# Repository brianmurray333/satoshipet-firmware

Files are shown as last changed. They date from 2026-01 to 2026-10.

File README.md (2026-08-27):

<h1 align="center">🐱⚡ Satoshi Pet Firmware</h1>

<p align="center">
  <strong>A cute hardware companion that reacts to your Bitcoin activity</strong>
</p>

<p align="center">
  <a href="#features">Features</a> •
  <a href="#hardware">Hardware</a> •
  <a href="#build-your-own">Build Your Own</a> •
  <a href="#flashing">Flashing</a> •
  <a href="#connecting">Connecting</a> •
  <a href="#license">License</a>
</p>

---

## What is Satoshi Pet?

Satoshi Pet is an open-source hardware device that makes Bitcoin tangible and fun. It's a virtual pet that lives on a small OLED screen and reacts to your Bitcoin balance:

- 🎉 **Celebrates** when you earn sats
- 🍕 **Needs feeding** with coins you earn
- 🎮 **Plays games** to stay happy
- 💤 **Sleeps** to save battery
- 📱 **Syncs** with your [Ganamos](https://ganamos.earth) wallet

Perfect for teaching kids about Bitcoin through interactive play, or just having a fun desk companion that shows your stack!

## Features

- **Real-time Balance Updates** - Your pet knows when you earn or spend sats
- **Virtual Economy** - Earn coins by earning Bitcoin, spend them on pet care
- **Mini Games** - Lightning-themed games to keep your pet happy
- **Job Notifications** - Get pinged when new jobs are posted in your groups
- **Battery Powered** - USB-C rechargeable, lasts for days
- **WiFi Connected** - Syncs automatically with your Ganamos account
- **Open Source** - Build your own from off-the-shelf parts!

## Hardware

### Bill of Materials (BOM)

| Part | Specification | Est. Cost | Where to Buy |
|---|---|---|---|
| **Heltec WiFi Kit 32 V3** | ESP32-S3 with 0.96" OLED | $15-20 | [AliExpress](https://www.aliexpress.com/item/1005006439587092.html), [Amazon](https://www.amazon.com/dp/B0BKVKVQ4S) |
| **LiPo Battery** | 3.7V, 1000-2000mAh, JST-PH 2.0 connector | $5-10 | Amazon, AliExpress |
| **Tactile Button** | 6mm through-hole (optional, for external button) | $0.50 | Any electronics store |
| **Piezo Buzzer** | 5V passive buzzer | $1 | Amazon, AliExpress |
| **3D Printed Case** | PLA filament | $2-5 | Print yourself or use a service |
| **USB-C Cable** | For charging and flashing | $3 | Anywhere |

**Total estimated cost: $25-40**

### Wiring Diagram

```
Heltec WiFi Kit 32 V3
├── GPIO 0  ← Built-in PRG button (primary button)
├── GPIO 2  ← External button (optional)
├── GPIO 48 → Piezo buzzer positive (+)
├── GND     → Piezo buzzer negative (-)
└── Battery → 3.7V LiPo via JST connector
```

The Heltec board has a built-in OLED display, so no additional wiring needed for the screen!

### 3D Printed Case

STL files for the enclosure are in the [`hardware/3d-models/`](hardware/3d-models/) directory:
- `case-top.stl` - Top shell
- `case-bottom.stl` - Bottom shell with battery compartment
- `button-cap.stl` - Optional button cap

Print settings: PLA, 0.2mm layer height, 20% infill

## Build Your Own

### Prerequisites

1. **Arduino IDE 2.x** or **PlatformIO**
2. **ESP32 Board Support** - Add Heltec ESP32 to your Arduino boards manager
3. **Required Libraries**:
   - `WiFiManager` by tzapu
   - `ArduinoJson` by Benoit Blanchon
   - `Heltec ESP32 Dev-Boards` board package

### Arduino IDE Setup

1. **Add Heltec Board Manager URL:**
   ```
   File → Preferences → Additional Board Manager URLs:
   https://github.com/Heltec-Aaron-Lee/WiFi_Kit_series/releases/download/0.0.9/package_heltec_esp32_index.json
   ```

2. **Install Board Package:**
   ```
   Tools → Board → Boards Manager → Search "Heltec" → Install
   ```

3. **Select Board:**
   ```
   Tools → Board → Heltec ESP32 Series Dev-Boards → WiFi Kit 32(V3)
   ```

4. **Install Libraries:**
   ```
   Tools → Manage Libraries → Search and install:
   - WiFiManager
   - ArduinoJson
   ```

## Flashing

1. Connect your Heltec board via USB-C

2. Open `firmware/satoshi_pet_heltec.ino` in Arduino IDE

3. Select the correct port:
   ```
   Tools → Port → /dev/cu.usbserial-* (Mac) or COM* (Windows)
   ```

4. Click **Upload** (→ button)

5. Wait for flashing to complete (~30 seconds)

## Connecting

### First-Time Setup

1. **Power on** your freshly flashed device
2. **Connect to WiFi**: The device creates a hotspot called `SatoshiPet-Setup`
   - Connect to this WiFi from your phone/laptop
   - A captive portal opens - enter your home WiFi credentials
3. **Get Pairing Code**: Device displays a 6-character code
4. **Link to Ganamos**:
   - Go to [ganamos.earth/connect-pet](https://ganamos.earth/connect-pet)
   - Create an account if you don't have one
   - Enter the pairing code to link your device

### Reconnecting

If you change WiFi networks:
1. Hold the button for 5+ seconds
2. Device enters WiFi setup mode
3. Connect to `SatoshiPet-Setup` and enter new credentials

## How It Works

```
┌─────────────────┐         ┌─────────────────┐
│  Satoshi Pet    │ ←WiFi→  │   Ganamos.earth │
│  (ESP32 Device) │         │   (Backend)     │
└────────┬────────┘         └────────┬────────┘
         │                           │
         │  1. Fetch config          │
         │  ──────────────────────→  │
         │  (balance, coins, jobs)   │
         │  ←──────────────────────  │
         │                           │
         │  2. Spend coins           │
         │  ──────────────────────→  │
         │  (feed, play game)        │
         │  ←──────────────────────  │
         │                           │
         │  3. Submit game score     │
         │  ──────────────────────→  │
         │  (leaderboard update)     │
         │  ←──────────────────────  │
         │                           │
```

The device polls the Ganamos API every 20-30 seconds to:
- Check your current balance
- Receive new coins when you earn Bitcoin
- Get notified of new jobs
- Sync pet care actions

## API Endpoints

The firmware communicates with these public endpoints:

| Endpoint | Purpose |
|---|---|
| `GET /api/device/config` | Fetch balance, coins, notifications |
| `POST /api/device/spend-coins` | Spend coins for feeding/games |
| `POST /api/device/game-score` | Submit game high scores |
| `GET /api/device/jobs` | Fetch available jobs |
| `POST /api/device/job-complete` | Mark a job as completed |

Note: Device identity is now sent in HTTP headers (`X-Device-Id`, `X-Pairing-Code`). The `deviceId` query parameter remains temporarily for one release to maintain compatibility with existing devices and backend versions.
## Troubleshooting

### Device won't connect to WiFi
- Hold button 5+ seconds to enter WiFi setup mode
- Make sure you're connecting to 2.4GHz network (not 5GHz)

### Pairing code not accepted
- Make sure you're entering the code exactly as shown
- Try power cycling the device to generate a new code

### Pet shows wrong balance
- Balance syncs every 20-30 seconds
- Check your internet connection
- Try pressing the button to force a refresh

### Screen stays off
- Device enters power-save mode after inactivity
- Press any button to wake up
- Check battery charge level

## Contributing

We welcome contributions! Please:

1. Fork this repository
2. Create a feature branch (`git checkout -b feature/amazing-feature`)
3. Commit your changes (`git commit -m 'Add amazing feature'`)
4. Push to the branch (`git push origin feature/amazing-feature`)
5. Open a Pull Request

## Community

- 🌐 **Website**: [satoshipet.com](https://satoshipet.com)
- 💬 **Discord**: Coming soon
- 🐦 **Twitter**: [@SatoshiPet](https://twitter.com/SatoshiPet)

## License

This project uses dual licensing:

- **Firmware** (`/firmware/*`): [Apache License 2.0](LICENSE) - Free to use, modify, and distribute with attribution
- **Hardware** (`/hardware/*`): [CERN-OHL-P v2](hardware/LICENSE-HARDWARE) - Open hardware license with patent protection

## Disclaimer

Satoshi Pet is a fun educational device. It does NOT store any Bitcoin private keys or have access to your funds. It only displays your Ganamos balance and reacts to changes.

---

<p align="center">
  Made with ❤️ by <a href="https://ganamos.earth">Ganamos</a>
</p>

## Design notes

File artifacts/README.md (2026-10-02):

# Battery and UX display previews

These images are code-based previews using the Heltec bitmap fonts and 128×64 layout, not live simulator screenshots. Values on the home screen are illustrative.

`ui-preview.png` shows the offline home screen, menu guidance, and hold confirmation from left to right. Individual previews also include the partially filled hold indicator.

Both firmware targets compile and the host regression checks pass. Live simulator verification was blocked by an expired Wokwi license. Battery current, GPIO wake behavior, and interaction timing still need validation on physical hardware.

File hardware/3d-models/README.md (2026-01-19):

# 3D Print Files

This folder contains STL files for the Satoshi Pet enclosure.

## Files

| File | Description |
|---|---|
| `case-top.stl` | Top shell with display cutout |
| `case-bottom.stl` | Bottom shell with battery compartment |
| `button-cap.stl` | Optional button extension |

## Print Settings

| Setting | Recommended |
|---|---|
| Material | PLA or PETG |
| Layer Height | 0.2mm |
| Infill | 15-20% |
| Supports | Yes (for button cutout) |
| Walls | 2-3 perimeters |

## Assembly

1. Print all parts
2. Insert Heltec board into bottom shell
3. Route battery and buzzer wires
4. Snap or screw top shell in place
5. (Optional) Add button cap

## Customization

STEP files are provided for modification. You can:
- Adjust dimensions for different batteries
- Add ventilation holes
- Customize button placement
- Add belt clip or lanyard hole

## Contributing

Have a better case design? PRs welcome!

---

**Note:** STL files will be added soon. For now, you can use the device without a case for testing.

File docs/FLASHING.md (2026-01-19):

# Flashing Guide

This guide walks you through flashing the Satoshi Pet firmware to a Heltec WiFi Kit 32 V3 board.

## Prerequisites

### Option 1: Arduino IDE (Recommended for beginners)

1. **Download Arduino IDE 2.x**
   - [arduino.cc/en/software](https://www.arduino.cc/en/software)

2. **Add Heltec Board Support**
   - Open Arduino IDE
   - Go to `File → Preferences`
   - In "Additional Board Manager URLs", add:
     ```
     https://github.com/Heltec-Aaron-Lee/WiFi_Kit_series/releases/download/0.0.9/package_heltec_esp32_index.json
     ```
   - Click OK

3. **Install Heltec ESP32 Board Package**
   - Go to `Tools → Board → Boards Manager`
   - Search for "Heltec"
   - Install "Heltec ESP32 Series Dev-Boards"

4. **Install Required Libraries**
   - Go to `Tools → Manage Libraries`
   - Install these libraries:
     - **WiFiManager** by tzapu (version 2.0.x)
     - **ArduinoJson** by Benoit Blanchon (version 7.x)

### Option 2: PlatformIO (Recommended for developers)

1. Install [VS Code](https://code.visualstudio.com/)
2. Install [PlatformIO Extension](https://platformio.org/install/ide?install=vscode)
3. Libraries will be installed automatically from `platformio.ini`

## Flashing Steps

### Step 1: Connect Your Board

1. Connect the Heltec WiFi Kit 32 V3 to your computer via USB-C
2. Wait for drivers to install (usually automatic)

### Step 2: Select Board and Port

**Arduino IDE:**
- `Tools → Board → Heltec ESP32 Series Dev-Boards → WiFi Kit 32(V3)`
- `Tools → Port → Select your port`
  - Mac: `/dev/cu.usbserial-*` or `/dev/cu.wchusbserial*`
  - Windows: `COM3`, `COM4`, etc.
  - Linux: `/dev/ttyUSB0` or `/dev/ttyACM0`

**PlatformIO:**
- The board is auto-detected, just click the Upload button

### Step 3: Open the Firmware

1. Open the `firmware/satoshi_pet_heltec.ino` file in Arduino IDE
2. All the `.cpp` and `.h` files in the same folder will be included automatically

### Step 4: Upload

**Arduino IDE:**
- Click the Upload button (→ arrow icon)
- Wait for compilation and upload (~30-60 seconds)
- You should see "Done uploading" when complete

**PlatformIO:**
- Click the Upload button in the bottom toolbar
- Or run `pio run --target upload`

### Step 5: Verify

1. Open Serial Monitor (`Tools → Serial Monitor`)
2. Set baud rate to `115200`
3. You should see boot messages and "Setup complete!"

## Troubleshooting

### "Port not found" or "No device detected"

1. Try a different USB cable (some cables are charge-only)
2. Try a different USB port
3. Install CH340 drivers manually:
   - [Windows Driver](http://www.wch.cn/download/CH341SER_EXE.html)
   - [Mac Driver](http://www.wch.cn/download/CH341SER_MAC_ZIP.html)

### "Upload failed" or "Timed out waiting for packet header"

1. Hold the `PRG` button on the board while clicking Upload
2. Release the button after you see "Connecting..."
3. Some boards require this manual boot mode entry

### "Board not supported" error

Make sure you installed the Heltec ESP32 board package, NOT the generic ESP32 package.

### Compilation errors

1. Make sure all files are in the same folder as `satoshi_pet_heltec.ino`
2. Make sure you installed both required libraries (WiFiManager, ArduinoJson)
3. Try `Sketch → Verify/Compile` first to see detailed errors

## First Boot

After successful flashing:

1. The board will display a splash screen
2. Then it will create a WiFi hotspot called `SatoshiPet-Setup`
3. Connect to this WiFi from your phone/laptop
4. A captive portal will open - enter your home WiFi credentials
5. The device will restart and display a 6-character pairing code

See the main README for pairing instructions.

## Updating Firmware

To update an already-configured device:

1. The device will remember WiFi credentials after update
2. Just flash the new firmware using the same steps above
3. Your pairing will be preserved (stored in flash memory)

## Factory Reset

To completely reset the device:

1. Hold the external button for 10+ seconds
2. The device will prompt "Factory Reset?"
3. Select "Yes" to confirm
4. All settings (WiFi, pairing) will be erased

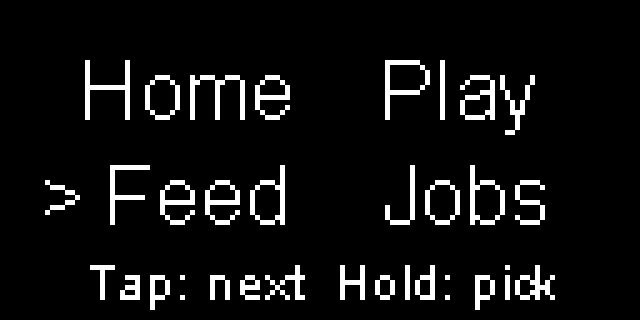
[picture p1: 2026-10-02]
artifacts/menu-preview.png

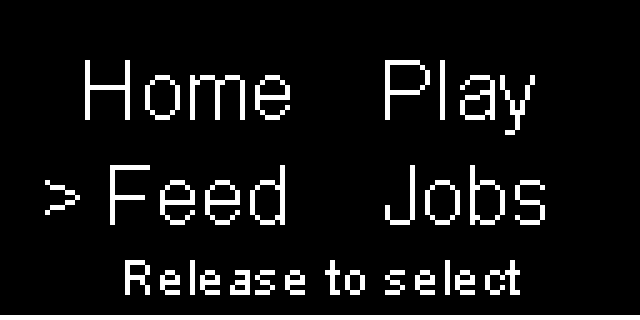
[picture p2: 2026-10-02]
artifacts/ready-preview.png

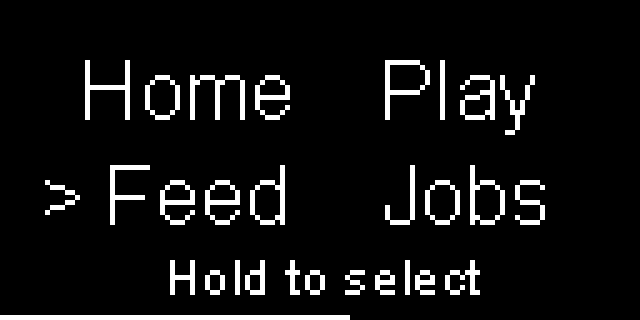
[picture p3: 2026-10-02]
artifacts/hold-preview.png

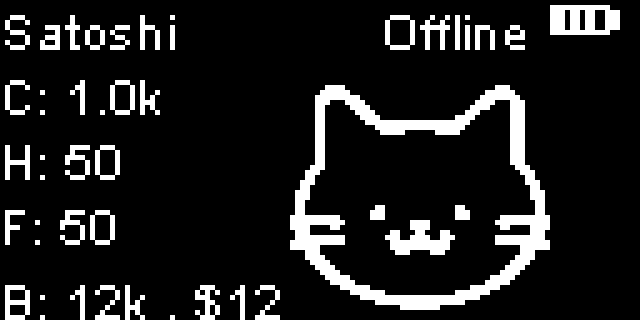
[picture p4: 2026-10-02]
artifacts/home-preview.png

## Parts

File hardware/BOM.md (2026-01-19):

# Bill of Materials (BOM)

Complete parts list for building your own Satoshi Pet.

## Core Components

### 1. Heltec WiFi Kit 32 V3

**The main board - ESP32-S3 with built-in OLED display**

| Spec | Value |
|---|---|
| MCU | ESP32-S3 |
| Display | 0.96" 128x64 OLED (SSD1306) |
| WiFi | 2.4GHz 802.11 b/g/n |
| USB | USB-C (programming & charging) |
| Battery | Built-in LiPo charger (JST-PH 2.0) |

**Where to Buy:**
- [Amazon US (Recommended)](https://www.amazon.com/dp/B07DKD79Y9?th=1) - ~$18
- [AliExpress - Official Heltec Store](https://www.aliexpress.com/item/1005006439587092.html) - ~$15

**⚠️ Important:** Make sure to get the **V3** version (ESP32-S3), not V2 or V1.

---

### 2. LiPo Battery

**3.7V Lithium Polymer battery with JST-PH 2.0mm connector**

| Spec | Recommended |
|---|---|
| Voltage | 3.7V (single cell) |
| Capacity | 1000-2000mAh |
| Connector | JST-PH 2.0mm (2-pin) |
| Size | ~50x30x8mm or smaller |

**Where to Buy:**
- [Amazon US (Recommended)](https://www.amazon.com/dp/B0FMY3M1YX?th=1) - ~$8
- [Adafruit 2000mAh](https://www.adafruit.com/product/2011) - $12
- Search "3.7V LiPo JST-PH 2.0" on AliExpress for cheaper options

**Battery Life Estimates:**
| Capacity | Active Use | Sleep Mode |
|---|---|---|
| 1000mAh | ~8 hours | ~3 days |
| 2000mAh | ~16 hours | ~7 days |

---

### 3. Piezo Buzzer

**5V passive piezo buzzer for sound effects**

| Spec | Value |
|---|---|
| Type | Passive (tone-driven) |
| Voltage | 3.3V-5V |
| Size | ~12mm diameter |

**Where to Buy:**
- [Amazon US (Recommended) - 10 pack](https://www.amazon.com/dp/B01N7NHSY6) - ~$6

**Note:** The firmware works with both active and passive buzzers. Active buzzers are simpler to use.

---

## Optional Components

### 4. External Button (Optional)

**Additional tactile button for easier pressing**

The Heltec board has a built-in PRG button (GPIO 0), but you can add an external button for a better case design.

| Spec | Value |
|---|---|
| Type | Tactile momentary switch |
| Size | 6mm x 6mm |
| Connection | Normally open (NO) |

**Where to Buy:**
- [Amazon US (Recommended)](https://www.amazon.com/dp/B07GN1K4HG) - ~$6

**Wiring:** Connect between GPIO 2 and GND (pull-up is internal).

---

### 5. Jumper Wires

**For connecting buzzer and button to the board**

| Spec | Value |
|---|---|
| Type | Male-to-female or male-to-male |
| Quantity | 4-6 wires needed |

**Where to Buy:**
- [Amazon US (Recommended)](https://www.amazon.com/EDGELEC-Breadboard-Optional-Assorted-Multicolored/dp/B07GD2BWPY) - ~$7

---

### 5. 3D Printed Case

**Enclosure to protect and display your Satoshi Pet**

| Spec | Recommended |
|---|---|
| Material | PLA or PETG |
| Layer Height | 0.2mm |
| Infill | 15-20% |
| Supports | May be needed for button cutout |

**Options:**
1. **Print yourself** - STL files in `hardware/3d-models/`
2. **Use a service** - Upload to JLCPCB, Shapeways, or local maker space
3. **Skip it** - The bare board works fine for testing!

---

## Tools Needed

| Tool | Purpose |
|---|---|
| Soldering iron | Connect buzzer wires |
| Solder | For buzzer connection |
| Wire (22-26 AWG) | Connect buzzer to board |
| USB-C cable | Programming and charging |
| Computer | For flashing firmware |

---

## Total Cost Estimate

| Item | Est. Cost |
|---|---|
| Heltec WiFi Kit 32 V3 | ~$18 |
| LiPo Battery | ~$8 |
| Buzzer (10 pack) | ~$6 |
| Buttons (pack) | ~$6 |
| Jumper Wires | ~$7 |
| 3D Printed Case | ~$2-5 |
| **Total** | **~$45-50** |

**Note:** Many parts come in multi-packs, so the per-unit cost is lower if building multiple devices. Sharing packs with friends can bring individual cost down to ~$30.

---

## Sourcing Tips

1. **AliExpress** - Cheapest, but 2-4 week shipping
2. **Amazon** - Fast shipping, slightly more expensive
3. **Adafruit/SparkFun** - Best quality, good documentation
4. **Local electronics store** - Immediate, but limited selection

## Alternative Boards

The firmware is designed for Heltec WiFi Kit 32 V3, but could be adapted for:

| Board | Compatibility | Notes |
|---|---|---|
| Heltec WiFi Kit 32 V2 | ⚠️ Partial | Different pin mapping |
| LILYGO T-Display S3 | ⚠️ Partial | Different display library |
| Generic ESP32 + SSD1306 | ⚠️ Partial | Manual wiring needed |

For best results, use the recommended Heltec WiFi Kit 32 V3.

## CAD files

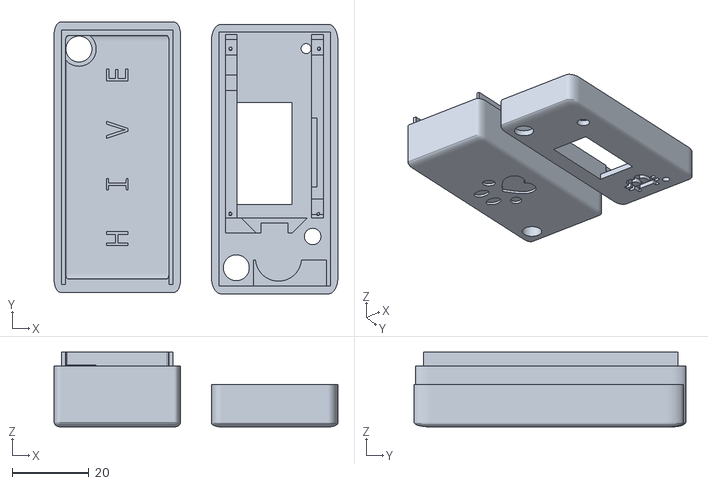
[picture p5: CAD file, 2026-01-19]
hardware/3d-models/case-v1.stl
74.0 x 70.8 x 19.5

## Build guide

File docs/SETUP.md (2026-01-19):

# Setup Guide

Complete guide to setting up your Satoshi Pet from scratch.

## Part 1: Hardware Assembly

### Required Parts

| Part | Notes |
|---|---|
| Heltec WiFi Kit 32 V3 | Main board with built-in OLED |
| 3.7V LiPo Battery | 1000-2000mAh recommended |
| Piezo Buzzer | 5V passive buzzer for sounds |
| 3D Printed Case | Optional but recommended |

### Wiring

```
Heltec Board          Component
────────────         ──────────
GPIO 48  ──────────► Buzzer (+)
GND      ──────────► Buzzer (-)
Battery Connector ◄── LiPo Battery (JST-PH 2.0)
```

**Note:** The Heltec board has a built-in battery connector and charging circuit. Just plug in the battery!

### Assembly

1. **Test before assembly** - Flash the firmware and test everything works
2. **Connect buzzer** - Solder wires to GPIO 48 (+) and GND (-)
3. **Connect battery** - Plug into the JST connector on the board
4. **Place in case** - Secure with screws or friction fit
5. **Done!**

## Part 2: First Boot

### Step 1: Power On

Press the reset button or plug in USB-C. You'll see:

1. **Ganamos splash logo** (2.5 seconds)
2. **"Fix your community / Earn Bitcoin"** tagline (2.5 seconds)
3. **WiFi Setup screen**

### Step 2: Configure WiFi

1. On your phone/laptop, look for WiFi network: `SatoshiPet-Setup`
2. Connect to it (no password needed)
3. A captive portal will automatically open
   - If it doesn't, open a browser and go to `192.168.4.1`
4. Click "Configure WiFi"
5. Select your home WiFi network
6. Enter the password
7. Click "Save"

The device will restart and connect to your WiFi.

### Step 3: Get Pairing Code

Once connected to WiFi, the device displays:

```
┌────────────────────┐
│   Pairing Code:    │
│                    │
│      ABC123        │
│                    │
│ Enter in Ganamos   │
└────────────────────┘
```

Write down this 6-character code.

### Step 4: Create Ganamos Account

1. Go to [ganamos.earth](https://ganamos.earth)
2. Click "Sign Up" and create an account
3. Verify your email

### Step 5: Connect Your Pet

1. Go to [ganamos.earth/connect-pet](https://ganamos.earth/connect-pet)
2. Enter the 6-character pairing code from your device
3. Choose a name for your pet
4. Select a pet type (cat, dog, rabbit, etc.)
5. Click "Connect"

Your device will show "Connected!" and your pet will appear!

## Part 3: Daily Use

### Button Controls

| Action | What Happens |
|---|---|
| **Short press** | Open menu |
| **Hold (3 sec)** | Select menu item / WiFi setup (if disconnected) |
| **Hold (10 sec)** | Factory reset prompt |

### Menu Options

- **Home** - Return to pet view
- **Play** - Play the Lightning Game (costs coins)
- **Feed** - Feed your pet (costs coins)
- **Jobs** - View available jobs

### Earning Coins

Coins are earned automatically when you:
- Receive Bitcoin deposits
- Get paid for completing jobs
- Receive internal transfers

Every sat you earn = coins for your pet!

### Pet Stats

- **Hunger** - Decreases over time, feed to restore
- **Happiness** - Decreases over time, play games to restore
- **Coins** - Your spendable balance for pet care

If both hunger and happiness hit 0, your pet "dies" (can be revived by feeding/playing).

## Part 4: Troubleshooting

### Device won't connect to WiFi

1. Make sure you're using a 2.4GHz network (not 5GHz)
2. Check that the password is correct
3. Try power cycling the device
4. Hold button 5 seconds to re-enter WiFi setup

### Pairing code not accepted

- Codes are case-insensitive (ABC123 = abc123)
- Make sure you're typing it exactly as shown
- If the code changed, use the new code on the device screen
- Power cycle to generate a fresh code

### Pet shows 0 balance but I have Bitcoin

- Balance syncs every 20-30 seconds
- Check your Ganamos account to verify the balance
- Try pressing the button to wake the device and force sync

### Screen is black

1. Press any button to wake from sleep mode
2. Check battery charge (plug in USB-C)
3. If still black, try holding reset button

### Sounds not working

- Check buzzer wiring (GPIO 48 and GND)
- Sounds are muted during "quiet hours" (8pm-8am)

## Part 5: Changing WiFi Networks

If you move or change routers:

1. Hold the button for 5+ seconds (when device is on)
2. Device enters WiFi setup mode
3. Connect to `SatoshiPet-Setup` hotspot
4. Enter new WiFi credentials
5. Device reconnects with same pairing

Your pet and coins are preserved!

## Part 6: Factory Reset

To completely wipe the device:

1. Hold external button for 10+ seconds
2. Screen shows "Factory Reset?"
3. Use short press to toggle between No/Yes
4. Hold to confirm selection
5. If "Yes", device erases all data and restarts

After factory reset:
- WiFi credentials are erased
- Pairing is erased
- A new pairing code is generated
- You'll need to pair again

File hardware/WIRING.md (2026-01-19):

# Wiring Guide

Detailed wiring instructions for Satoshi Pet.

## Pin Reference

### Heltec WiFi Kit 32 V3 Pinout

```
                    ┌─────────────┐
                    │   USB-C     │
                    │             │
              3.3V ─┤             ├─ GND
               EN ─┤             ├─ GPIO 35 (RGB LED)
           GPIO 36 ─┤             ├─ GPIO 0 (PRG Button)
           GPIO 26 ─┤             ├─ GPIO 4
           GPIO 33 ─┤             ├─ GPIO 16
           GPIO 32 ─┤             ├─ GPIO 17
           GPIO 35 ─┤             ├─ GPIO 5
           GPIO 34 ─┤             ├─ GPIO 18
               VIN ─┤             ├─ GPIO 19
               GND ─┤             ├─ GPIO 21
           GPIO 15 ─┤             ├─ GPIO 3
            GPIO 2 ─┤             ├─ GPIO 1
            GPIO 0 ─┤             ├─ GPIO 22
            GPIO 4 ─┤             ├─ GPIO 23
                    │   ┌─────┐   │
                    │   │OLED │   │
                    │   │     │   │
                    │   └─────┘   │
                    │             │
                    │  [RST][PRG] │
                    └─────────────┘
                      ↑       ↑
                   Reset   Button
                   Button  (GPIO 0)
```

## Connections

### Required: Piezo Buzzer

```
Heltec Board                    Buzzer
────────────                   ────────
GPIO 48  ───────────────────►  + (positive)
GND      ───────────────────►  - (negative)
```

**Soldering Steps:**
1. Cut two pieces of wire (~5cm each)
2. Strip both ends of each wire
3. Solder one wire to GPIO 48 pad
4. Solder other wire to any GND pad
5. Connect to buzzer (polarity matters for some buzzers)

### Required: Battery

```
Heltec Board                    Battery
────────────                   ────────
JST Connector ◄─────────────►  LiPo 3.7V (JST-PH 2.0)
```

**No soldering needed!** The battery plugs directly into the JST connector on the board.

**⚠️ Warning:** Double-check battery polarity. The connector should only fit one way, but forcing it backwards can damage the board.

### Optional: External Button

```
Heltec Board                    Button
────────────                   ────────
GPIO 2   ───────────────────►  Pin 1
GND      ───────────────────►  Pin 2
```

The internal pull-up resistor is enabled in firmware, so no external resistor needed.

## Schematic

```
                                    ┌─────────────────┐
                                    │                 │
                                    │  Heltec V3      │
                                    │  WiFi Kit 32    │
                                    │                 │
    ┌──────────┐                    │                 │
    │  LiPo    │◄──JST Connector───►│  Battery In     │
    │ Battery  │                    │                 │
    │  3.7V    │                    │                 │
    └──────────┘                    │                 │
                                    │  GPIO 48 ───────┼────► Buzzer (+)
    ┌──────────┐                    │                 │
    │  Button  │────GPIO 2─────────►│  GPIO 2         │
    │ (ext.)   │────GND────────────►│  GND ───────────┼────► Buzzer (-)
    └──────────┘                    │                 │
                                    │                 │
                                    │  Built-in:      │
                                    │  - 128x64 OLED  │
                                    │  - PRG Button   │
                                    │  - RGB LED      │
                                    │  - USB-C        │
                                    │                 │
                                    └─────────────────┘
```

## GPIO Summary

| GPIO | Function | Notes |
|---|---|---|
| 0 | PRG Button (built-in) | Primary button, active LOW |
| 2 | External Button | Optional, active LOW with pull-up |
| 48 | Buzzer | PWM output for tones |
| 35 | RGB LED (built-in) | Used for notifications |
| 1 | Battery ADC | Reads battery voltage |
| 37 | ADC Control | Enables battery voltage divider |
| 21 | Vext | Display power control |

## Display (Built-in)

The OLED display is pre-wired on the Heltec board:

| Signal | GPIO |
|---|---|
| SDA | Fixed (internal) |
| SCL | Fixed (internal) |
| RST | Fixed (internal) |

No external wiring needed for the display!

## Power

### USB-C Charging

- The Heltec board has a built-in LiPo charger
- Plug in USB-C to charge the battery
- Red LED = charging, off = charged

### Battery Life Tips

1. **Larger battery = longer life** (2000mAh recommended)
2. **Display auto-sleeps** after 3 minutes of inactivity
3. **WiFi power-saving** kicks in during sleep mode

## Testing Your Wiring

After assembly, test with Serial Monitor (115200 baud):

```
=== Battery Quick Test ===
Voltage: 4.05 V
==========================
```

If you see reasonable voltage (3.5-4.2V), battery is connected correctly.

For buzzer, the device will play sounds when:
- Button is pressed (chirp)
- New sats arrive (celebration tune)
- Pet needs attention (sad sound)

## Troubleshooting

### No display

- Check that the display ribbon cable is seated properly
- Try pressing the RST button
- Make sure you selected the correct board in Arduino IDE

### No sound

- Check buzzer polarity
- Verify GPIO 48 connection
- Some buzzers are polarized - try swapping + and -

### Battery not charging

- Check JST connector polarity
- Try a different USB-C cable
- The charging circuit may be damaged if polarity was reversed

### Button not working

- Check GPIO 2 connection for external button
- Built-in PRG button should always work
- Serial Monitor shows button presses if wired correctly

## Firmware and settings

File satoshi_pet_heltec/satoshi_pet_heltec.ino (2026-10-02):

  #include <Wire.h>
  #include "HT_SSD1306Wire.h"
  #include <WiFiManager.h>
  #include <HTTPClient.h>
  #include <ArduinoJson.h>
  #include <time.h>
  #include "config.h"
  #include "pet_blob.h"
  #include "economy.h"
  #include "button_handler.h"
  #include "display_assets.h"
  #include "espnow_comm.h"
  #include "pickleball.h"
  #include <esp_task_wdt.h>  // Watchdog timer support (framework auto-initializes)
  #include <esp_idf_version.h>
  #include <esp_sleep.h>
  #include <driver/gpio.h>

  // Keep declarations explicit so this sketch builds consistently with both
  // Arduino IDE and non-IDE toolchains such as PlatformIO/Wokwi.
  bool isQuietHours();
  void playLowBatterySound();
  void renderLowBatteryWarning(SSD1306Wire &display, int batteryPercent);
  void renderOnboardingStep(SSD1306Wire &display, int step, String petName);
  void renderDeathWarning(SSD1306Wire &display, String petName);
  void renderHungerWarning(SSD1306Wire &display, String petName, int fullness);
  void renderSadnessWarning(SSD1306Wire &display, String petName, int happiness);
  void handleFactoryReset();
  void playButtonChirp();
  void playMenuSelectTone();
  void VextON();
  void playDeathSound();
  void playSadSound();

  // Debug logging - comment out to disable verbose logs and save memory
  // #define DEBUG_LOGGING

  #define Vext 21
  #define BUTTON_PIN_PRG 0      // PRG button
  #define BUTTON_PIN_EXTERNAL 2 // External button
  #define RGB_LED 35            // Heltec V3 RGB LED pin
  #define BUZZER_PIN 48         // Piezo buzzer pin
  #define ADC_CTRL 37           // GPIO37 - Control pin to enable battery voltage divider
  #define VBAT_PIN 1            // GPIO1 - Battery voltage ADC reading pin (ADC1_CH0)
  // Heltec WiFi Kit 32 V3 (ESP32-S3) voltage divider: 100kΩ/390kΩ = multiply by 4.9

  #ifdef WOKWI_SIMULATOR
  // Wokwi's standalone SSD1306 part has no reset pin. The real Heltec OLED
  // does, so preserve the hardware behavior in the normal build.
  SSD1306Wire display(0x3c, 400000, SDA_OLED, SCL_OLED, GEOMETRY_128_64, -1);
  #else
  SSD1306Wire display(0x3c, 500000, SDA_OLED, SCL_OLED, GEOMETRY_128_64, RST_OLED);
  #endif

  // Function to dim OLED display (SSD1306 commands)
  // Based on Heltec forum: contrast control may not work well on V2.0+ boards
  // Using multiple SSD1306 commands for better dimming effect
  void setOLEDContrast(uint8_t contrast) {
    Wire.beginTransmission(0x3c);
    Wire.write(0x00); // Command mode
    
    // Set contrast (0x81)
    Wire.write(0x81);
    Wire.write(contrast);
    
    // Set precharge period (0xD9) - affects brightness
    // Lower values = dimmer, but too low causes flicker
    if (contrast < 128) {
      Wire.write(0xD9);
      Wire.write(0x11); // Dim: phase 1 = 1, phase 2 = 1 (minimum)
    } else {
      Wire.write(0xD9);
      Wire.write(0xF1); // Bright: phase 1 = 15, phase 2 = 1 (default)
    }
    
    // Set VCOMH deselect level (0xDB) - affects brightness
    if (contrast < 128) {
      Wire.write(0xDB);
      Wire.write(0x20); // Dim: 0.77 * VCC (lower voltage = dimmer)
    } else {
      Wire.write(0xDB);
      Wire.write(0x40); // Bright: 0.83 * VCC (default)
    }
    
    Wire.endTransmission();
    
    // Also try library method as backup
    display.setContrast(contrast);
  }

  bool isPaired = false;  
  String pendingPickleballGameId = "";
  String pendingPickleballHostMac = "";
  unsigned long lastUpdate = 0;
  const unsigned long DEFAULT_UPDATE_INTERVAL = 60000; // Default to one poll/minute to reduce radio wakeups
  const unsigned long MIN_UPDATE_INTERVAL = 60000;     // Never let server config create a battery-heavy poll loop
  bool buttonPressed = false;
  bool consumeButtonUntilRelease = false;
  bool lastSyncSucceeded = false;
  unsigned long buttonPressTime = 0;
  unsigned long lastButtonPress = 0;
  bool hadSavedConfigOnBoot = false; // Track if we loaded saved config on boot
  int consecutiveConfig404s = 0;
  const int CONFIG_404_THRESHOLD = 3;
  // WiFi reconnection with exponential backoff
  unsigned long lastWifiReconnectAttempt = 0;
  int wifiReconnectAttempts = 0;
  const int WIFI_MAX_QUICK_RETRIES = 5;  // After 5 quick failures, slow down significantly
  const unsigned long WIFI_MIN_BACKOFF_MS = 5000;  // Start with 5 seconds between attempts
  const unsigned long WIFI_MAX_BACKOFF_MS = 300000;  // Max 5 minutes between attempts
  bool wifiConfigPortalRequested = false;  // Flag to enter WiFi setup mode
  enum ButtonSource {
    BUTTON_SOURCE_NONE,
    BUTTON_SOURCE_EXTERNAL,
    BUTTON_SOURCE_PRG,
    BUTTON_SOURCE_BOTH
  };
  ButtonSource lastButtonSource = BUTTON_SOURCE_NONE;
  void logCurrentPairingState();
  bool confirmFactoryReset();
  void renderFactoryResetPrompt(int selectedOption);

  // Menu system state
  bool inMenuMode = false;
  int currentMenuOption = 0; // 0=Feed, 1=Play, 2=Home
  unsigned long lastMenuCycle = 0;

  // Screensaver settings for power saving
#ifdef WOKWI_SIMULATOR
  // Accelerate power-state transitions so sleep/wake can be covered quickly.
  const unsigned long SCREENSAVER_TIMEOUT = 15000;
  const unsigned long BITCOIN_FACTS_TIMEOUT = 30000;
  const unsigned long SCREENSAVER_DISPLAY_OFF_TIMEOUT = 45000;
  const unsigned long BATTERY_CHECK_INTERVAL = 5000;
#else
  const unsigned long SCREENSAVER_TIMEOUT = 30000; // Dim after 30 seconds
  const unsigned long BITCOIN_FACTS_TIMEOUT = 45000; // Brief facts screen
  const unsigned long SCREENSAVER_DISPLAY_OFF_TIMEOUT = 60000; // Off after one minute
  const unsigned long BATTERY_CHECK_INTERVAL = 60000;
#endif
  float cachedBatteryVoltage = 0.0f;
  unsigned long lastBatteryVoltageSample = 0;
  uint8_t NORMAL_BRIGHTNESS = 255;  // Full brightness (non-const so it can be extern)
  uint8_t DIM_BRIGHTNESS = 10;      // Dimmed brightness (much lower for V2.0+ boards that don't respond well to contrast)
  bool isScreensaverActive = false;
  bool isBitcoinFactsActive = false;
  bool isDisplayOff = false;
  int bitcoinFactsForSession[3] = {0, 1, 2}; // 3 facts to show in this session
  int onboardingStep = 0;
  unsigned long bitcoinFactsStartTime = 0; // When facts mode started  // Track if display is completely off (power saving mode)

  // Low battery warning state
  bool isLowBatteryWarningActive = false;
  unsigned long lowBatteryWarningStartTime = 0;
  bool lowBatteryAlertPlayed = false; // Prevent repeated alerts

  const unsigned long HOLD_PRESS_MIN = 700;
  const unsigned long SHORT_PRESS_MAX = HOLD_PRESS_MIN - 1;
  const unsigned long VERY_LONG_PRESS = 10000; // 10 seconds to prevent accidental factory reset

  bool notificationActive = false;
  bool notificationReturnToSleep = false;
  unsigned long notificationStarted = 0;
  const unsigned long NOTIFICATION_DURATION = 6000;
  int petWarning = 0;

  void wakeForNotification() {
    notificationReturnToSleep |= isScreensaverActive || isDisplayOff;
    notificationActive = true;
    notificationStarted = millis();
    if (isDisplayOff) {
      VextON();
      delay(100);
      display.init();
    }
    isDisplayOff = isScreensaverActive = isBitcoinFactsActive = false;
    setOLEDContrast(NORMAL_BRIGHTNESS);
  }

  void renderHoldProgress() {
    if (!buttonPressed) return;
    static unsigned long lastFrame = 0;
    unsigned long now = millis();
    if (now - lastFrame < 50) return;
    lastFrame = now;
    unsigned long elapsed = now - buttonPressTime;
    display.setColor(BLACK);
    display.fillRect(0, 49, 128, 15);
    display.setColor(WHITE);
    display.setFont(ArialMT_Plain_10);
    display.setTextAlignment(TEXT_ALIGN_CENTER);
    display.drawString(64, 49, elapsed < HOLD_PRESS_MIN ? "Hold to select" : "Release to select");
    display.fillRect(0, 63, min(128UL, elapsed * 128 / HOLD_PRESS_MIN), 1);
    display.display();
  }

  int getBatteryPercentage() {
    float voltage = getBatteryVoltage();
    
    // Non-linear LiPo discharge curve (more accurate than simple linear mapping)
    // Based on typical single-cell LiPo discharge characteristics
    int percentage;
    
    if (voltage >= 4.15) {
      percentage = 100;  // 4.15V+ = 100%
    } else if (voltage >= 4.0) {
      // 4.0-4.15V = 85-100% (top 15% is rapid)
      percentage = 85 + (int)((voltage - 4.0) / 0.15 * 15);
    } else if (voltage >= 3.85) {
      // 3.85-4.0V = 60-85% (gradual decline)
      percentage = 60 + (int)((voltage - 3.85) / 0.15 * 25);
    } else if (voltage >= 3.7) {
      // 3.7-3.85V = 40-60% (mid range, flatter curve)
      percentage = 40 + (int)((voltage - 3.7) / 0.15 * 20);
    } else if (voltage >= 3.5) {
      // 3.5-3.7V = 15-40% (steeper drop)
      percentage = 15 + (int)((voltage - 3.5) / 0.2 * 25);
    } else if (voltage >= 3.2) {
      // 3.2-3.5V = 5-15% (getting low)
      percentage = 5 + (int)((voltage - 3.2) / 0.3 * 10);
    } else if (voltage >= 3.0) {
      // 3.0-3.2V = 0-5% (critical low)
      percentage = (int)((voltage - 3.0) / 0.2 * 5);
    } else {
      percentage = 0;  // Below 3.0V = dead
    }
    
    // Clamp between 0-100
    if (percentage > 100) percentage = 100;
    if (percentage < 0) percentage = 0;
    
    // Log if voltage seems inconsistent
    if (voltage > 4.3) {
      Serial.println("⚠️  Warning: Voltage > 4.3V - may be charging or ADC issue");
    }
    if (voltage < 3.0 && voltage > 0.1) {
      Serial.println("⚠️  Warning: Voltage < 3.0V - battery critically low");
    }
    
    return percentage;
  }

  // Returns battery level 0-3 for icon display
  int getBatteryLevel() {
    float voltage = getBatteryVoltage();
    if (voltage >= 3.9) return 3;      // Full
    else if (voltage >= 3.7) return 2; // Medium  
    else if (voltage >= 3.5) return 1; // Low
    else return 0;                     // Critical
  }

  // Charging detection requires a hardware status signal, not a voltage guess.
  bool isBatteryCharging() {
    // Voltage alone cannot distinguish a full battery from active charging.
    return false;
  }

  // Helper function to read battery once
  float readVbatOnce() {
    // Use calibrated analogReadMilliVolts for better accuracy
    float v_meas = analogReadMilliVolts(VBAT_PIN) / 1000.0;
    return v_meas * 4.9;  // 100kΩ/(100kΩ+390kΩ) divider = multiply by 4.9
  }

  float getBatteryVoltage() {
    unsigned long now = millis();
    if (cachedBatteryVoltage > 0.0f &&
        now - lastBatteryVoltageSample < BATTERY_CHECK_INTERVAL) {
      return cachedBatteryVoltage;
    }

    // Brief wait for voltage to settle after any WiFi transmission
    delay(10);
    
    // Re-initialize ADC config (can reset after WiFi init or deep sleep)
    analogReadResolution(12);
    analogSetAttenuation(ADC_11db);
    
    // Heltec's V3 ADC control is active-high: enable it only while sampling.
    pinMode(ADC_CTRL, OUTPUT);
    digitalWrite(ADC_CTRL, HIGH);
    delay(5);
    
    // Debug: Read raw ADC values
    int rawADC = analogRead(VBAT_PIN);
    int rawMillivolts = analogReadMilliVolts(VBAT_PIN);
    
    Serial.println("🔋 ADC Debug: pin=" + String(VBAT_PIN) + " ctrl=" + String(ADC_CTRL));
    Serial.println("   Raw ADC value: " + String(rawADC) + " (0-4095 range)");
    Serial.println("   Raw millivolts: " + String(rawMillivolts) + " mV");
    Serial.println("   After 4.9x multiplier: " + String(rawMillivolts / 1000.0 * 4.9, 2) + " V");
    
    // Average 4 samples for stable reading (reduced from 8 for faster response)
    float sum = 0;
    for (int i = 0; i < 4; i++) {
      sum += readVbatOnce();
      delay(1);
    }
    float rawVoltage = sum / 4.0;
    
    // Apply Exponential Moving Average (EMA) filter for stable readings
    static float smoothedVoltage = 0;
    if (smoothedVoltage == 0) {
      // First reading - initialize with current value
      smoothedVoltage = rawVoltage;
    } else {
      // EMA: 85% old value + 15% new value (smooth but responsive)
      smoothedVoltage = (0.85 * smoothedVoltage) + (0.15 * rawVoltage);
    }
    
    float voltage = smoothedVoltage;
    cachedBatteryVoltage = voltage;
    lastBatteryVoltageSample = now;

    // Disable the divider between samples so its resistor
    // path does not continuously drain the battery.
    digitalWrite(ADC_CTRL, LOW);
    
    // Sanity check for disconnected battery or bad reading
    if (voltage < 0.1) {
      Serial.println("⚠️  Warning: Battery read near 0 V – check cable or battery health.");
    } else if (voltage < 3.0 && voltage > 0.1) {
      Serial.println("⚠️  Warning: Voltage < 3.0V - battery critically low");
    }
    
    Serial.println("Battery: Raw=" + String(rawVoltage, 2) + "V Smoothed=" + String(voltage, 2) + "V");
    
    if (voltage > 4.15) {
      Serial.println("ℹ️  Battery appears nearly full - charging LED may be off due to charge complete");
    }
    
    return voltage;
  }

  void playSatsEarnedSound() {
    if (isQuietHours()) return;
    // Uplifting 8-bit style melody for earning sats
    int melody[] = {523, 587, 659, 784, 880, 1047};
    int durations[] = {100, 100, 100, 150, 150, 300};
    
    for (int i = 0; i < 6; i++) {
      tone(BUZZER_PIN, melody[i], durations[i]);
      delay(durations[i] + 20);
      noTone(BUZZER_PIN);
    }
  }

  void playFixRejectedSound() {
    if (isQuietHours()) return;  // Silent during quiet hours
    // Sad descending tone - opposite of the celebration melody
    int melody[] = {880, 784, 659, 587, 523, 392};
    int durations[] = {150, 150, 150, 200, 200, 400};
    
    for (int i = 0; i < 6; i++) {
      tone(BUZZER_PIN, melody[i], durations[i]);
      delay(durations[i] + 30);
      noTone(BUZZER_PIN);
    }
  }

  void displayPairingCode() {
  #ifdef DEBUG_LOGGING
    Serial.print(F("Pairing code: "));
    Serial.println(maskForLog(pairingCode));
  #endif
    display.clear();
    display.setFont(ArialMT_Plain_10);
    display.setTextAlignment(TEXT_ALIGN_CENTER);
    display.drawString(64, 5, "Pairing Code:");
    display.setFont(ArialMT_Plain_16);
    display.drawString(64, 25, pairingCode);
    display.setFont(ArialMT_Plain_10);
    display.drawString(64, 50, "Enter in Ganamos app");
    display.display();
  }
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
  void loop() {
    // DISABLED: Watchdog feed causing boot loop
    // esp_task_wdt_reset();
      esp_task_wdt_reset();  // Feed watchdog at start of every loop iteration
    // Ensure WiFi stays off if we're in offline mode (prevents background blocking)
    static bool wifiDisabled = false;
    if (!wifiDisabled && WiFi.status() != WL_CONNECTED) {
      if (WiFi.getMode() != WIFI_OFF) {
        Serial.println(F("Forcing WiFi OFF to prevent blocking"));
        WiFi.disconnect(true);
        WiFi.mode(WIFI_OFF);
      }
      wifiDisabled = true;
    }
    
    static unsigned long lastLoopDebug = 0;
    static unsigned long lastLoopTime = 0;
    unsigned long now = millis();
    if (notificationActive && now - notificationStarted >= NOTIFICATION_DURATION) {
      notificationActive = false;
      petWarning = 0;
      isLowBatteryWarningActive = false;
      showCelebration = false;
      showNewJobNotification = false;
      showRejection = false;
      digitalWrite(RGB_LED, LOW);
      if (notificationReturnToSleep) {
        isDisplayOff = isScreensaverActive = true;
        isBitcoinFactsActive = false;
        VextOFF();
        WiFi.disconnect(true);
        WiFi.mode(WIFI_OFF);
      }
      notificationReturnToSleep = false;
    }
    
    // Warn if loop is running slowly (taking more than 500ms between iterations)
    if (!isDisplayOff && lastLoopTime > 0 && (now - lastLoopTime) > 500) {
      Serial.print(F("SLOW LOOP: "));
      Serial.print(now - lastLoopTime);
      Serial.println(F("ms since last iteration"));
    }
    lastLoopTime = now;
    
    // Debug: track time through loop sections
    unsigned long sectionStart = millis();
    
    // Log loop alive status every 30 seconds to help debug reboots
  #ifdef DEBUG_LOGGING
    if (now - lastLoopDebug > 30000) {
      Serial.print(F("Loop alive, uptime: "));
      Serial.print(now/1000);
      Serial.println(F("s"));
      lastLoopDebug = now;
    }
  #endif
    static int cachedBatteryPct = -1; // Cache battery percentage (-1 = not initialized)
    static unsigned long lastBatteryCheck = 0;
    
    // Initialize battery on first loop, then sample at the target-specific cadence.
    if (cachedBatteryPct < 0 || (now - lastBatteryCheck > BATTERY_CHECK_INTERVAL)) {
      cachedBatteryPct = getBatteryPercentage();
      lastBatteryCheck = now;
      
      // Trigger low battery warning at 10% (only once per charge cycle)
      if (cachedBatteryPct <= 10 && !lowBatteryAlertPlayed && !isLowBatteryWarningActive) {
        Serial.println("🔋 LOW BATTERY WARNING - waking display to show warning");
        
        wakeForNotification();
        
        // Enter low battery warning mode
        isLowBatteryWarningActive = true;
        lowBatteryWarningStartTime = now;
        isScreensaverActive = false;
        isBitcoinFactsActive = false;
        isDisplayOff = false;
        
        // Play warning sound
        playLowBatterySound();
        lowBatteryAlertPlayed = true;
        
        // Show the warning screen
        renderLowBatteryWarning(display, cachedBatteryPct);
      }
    }
    
    // Enter ultra-low-power mode only at 5% (critical battery)
    // BUT only if user hasn't interacted recently - let normal screensaver flow handle sleep
    // This ensures button press always wakes device for full timeout period
    if (cachedBatteryPct <= 5 && !isDisplayOff && !isLowBatteryWarningActive) {
      // Only force low-power if we've already gone through the screensaver timeout
      // (i.e., user hasn't pressed a button recently)
      if (!notificationActive && !inMenuMode && now - lastButtonPress > SCREENSAVER_DISPLAY_OFF_TIMEOUT) {
        Serial.println("🔋 CRITICAL BATTERY (5%) - entering ultra-low-power mode");
        isScreensaverActive = true;
        isDisplayOff = true;
        VextOFF();
        WiFi.disconnect(true);
        WiFi.mode(WIFI_OFF);
        // Will only wake for button press or poll every 5 minutes
      }
    }
    
    // Reset low battery alert flag when battery charged above 20%
    if (cachedBatteryPct > 20) {
      lowBatteryAlertPlayed = false;
    }
    
    // Multi-stage sleep transition: screensaver → facts → display OFF
      if (!notificationActive && !inMenuMode && !buttonPressed && !isScreensaverActive && (now - lastButtonPress > SCREENSAVER_TIMEOUT)) {
      isScreensaverActive = true;
      isBitcoinFactsActive = false;
      isDisplayOff = false;
      setOLEDContrast(DIM_BRIGHTNESS);
      // Enable WiFi power saving when idle (saves 20-40mA)
      if (WiFi.status() == WL_CONNECTED) {
        WiFi.setSleep(true);
      }
  #ifdef DEBUG_LOGGING
      Serial.println(F("Entering screensaver"));
  #endif
    }
    
    // Briefly show facts before display-off.
    if (isScreensaverActive && !isBitcoinFactsActive && !isDisplayOff && (now - lastButtonPress > BITCOIN_FACTS_TIMEOUT)) {
      isBitcoinFactsActive = true;
      bitcoinFactsStartTime = now;
      
      // Pick 3 random facts to show (20 seconds each = 60 seconds total)
      for (int i = 0; i < 3; i++) {
        bitcoinFactsForSession[i] = random(0, BITCOIN_FACTS_COUNT);
      }
  #ifdef DEBUG_LOGGING
      Serial.println(F("Entering Bitcoin facts mode"));
  #endif
    }
    
    // End the idle display period.
    if (isBitcoinFactsActive && !isDisplayOff && (now - lastButtonPress > SCREENSAVER_DISPLAY_OFF_TIMEOUT)) {
      isDisplayOff = true;
      VextOFF();  // Turn display OFF completely to save power
      
      // Disconnect WiFi to save significant power
      WiFi.disconnect(true);
      WiFi.mode(WIFI_OFF);
  #ifdef DEBUG_LOGGING
      Serial.println(F("Display OFF, WiFi OFF (power saving)"));
  #endif
    }
    
    // Debug timing checkpoint
    if (millis() - sectionStart > 100) {
      Serial.print(F("SLOW: Battery section took "));
      Serial.print(millis() - sectionStart);
      Serial.println(F("ms"));
    }
    sectionStart = millis();
    
    if (!isPaired) {
      // Check every 5 seconds if we're now paired
      if (now - lastUpdate > 5000) {
        lastUpdate = now;
        
        extern int getLastHttpCode();
        bool fetchSuccess = fetchGanamosConfig();
        
        if (fetchSuccess) {
          isPaired = true;
          saveDeviceConfig(); // SAVE TO FLASH!
          Serial.println("Successfully paired and saved to flash memory!");
          consecutiveConfig404s = 0;
          
          display.clear();
          display.setFont(ArialMT_Plain_10);
          display.setTextAlignment(TEXT_ALIGN_CENTER);
          display.drawString(64, 20, "Connected!");
          display.drawString(64, 35, ganamosConfig.petName);
          display.display();
          delay(2000);
          
          // Start onboarding flow
          onboardingStep = 1;
          renderOnboardingStep(display, onboardingStep, ganamosConfig.petName);
        } else {
          // Check if we got a 404 - only regenerate if we had saved config that's now invalid
          // If we're starting fresh (no saved config), 404 is expected - don't regenerate code
          static bool hasHandledSavedConfig404 = false;
          bool got404 = (getLastHttpCode() == 404);
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

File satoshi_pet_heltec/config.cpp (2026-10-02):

#include "config.h"
#include <HTTPClient.h>
#include <ArduinoJson.h>
#include <WiFi.h>
#include <WiFiClientSecure.h> 
#include <WiFiClient.h>
#include <freertos/FreeRTOS.h>
#include <freertos/task.h>


// Removed unused legacy DeviceConfig and loadConfig()

GanamosConfig ganamosConfig = {
  "",          // deviceId
  "Pet",       // petName
  "cat",       // petType
  "",          // userName
  0,           // balance
  0,           // coins
  0.0,         // btcPrice
  20000,       // pollInterval
  "",          // serverUrl
  "",          // lastMessage
  "",          // lastMessageType
  "",          // lastPostTitle
  "",          // lastSenderName
  100,         // gameCost (default: 100 coins per game)
  15,          // gameReward (default: 15 happiness per game)
  "",          // lastRejectionId
  "",          // rejectionMessage
  ""           // rejectionPostTitle
};
int consecutiveFailures = 0;
int lastHttpCode = 0; // Track last HTTP response code

// Attach device identity headers to a request
void attachIdentityHeaders(HTTPClient& http) {
  // Send device identity via headers (primary)
  if (ganamosConfig.deviceId.length() > 0) {
    http.addHeader("X-Device-Id", ganamosConfig.deviceId);
  }
  if (pairingCode.length() > 0) {
    http.addHeader("X-Pairing-Code", pairingCode);
  }
}

// Redact secrets for logs: show first 4 characters only
String maskForLog(const String& value) {
  if (value.length() == 0) return "";
  int visible = value.length() < 4 ? value.length() : 4;
  return value.substring(0, visible) + "****";
}

// Safe offline defaults match the live server configuration.
EconomyConfig economyConfig = {
  40.0,        // hungerDecayPer24h
  25.0         // happinessDecayPer24h
};

// Jobs data - cached from server
Job cachedJobs[MAX_JOBS];
int cachedJobCount = 0;
String lastSeenJobId = "";

// Format sats with k/M suffix for compact display
String formatSatsShort(int sats) {
  if (sats >= 1000000) {
    return String(sats / 1000000.0, 1) + "M";
  } else if (sats >= 10000) {
    // 10k+ show without decimal: "15k"
    return String(sats / 1000) + "k";
  } else if (sats >= 1000) {
    // 1k-9.9k show with decimal: "1.5k"
    return String(sats / 1000.0, 1) + "k";
  }
  return String(sats);
}

bool fetchJobs() {
  // Check WiFi status first
  if (WiFi.status() != WL_CONNECTED) {
    Serial.println("fetchJobs: WiFi not connected");
    return false;
  }
  
  if (ganamosConfig.deviceId.length() == 0) {
    Serial.println("fetchJobs: No deviceId");
    return false;
  }
  
  WiFiClientSecure *client = new WiFiClientSecure;
  if (!client) {
    return false;
  }
  
  HTTPClient http;
  
  client->setInsecure();
  client->setTimeout(5000);
  client->setHandshakeTimeout(5);
  
  String url = "https://www.ganamos.earth/api/device/jobs?deviceId=" + ganamosConfig.deviceId;
  
  delay(100);
  if (!http.begin(*client, url)) {
    delete client;
    return false;
  }
  
  http.setTimeout(5000);
  http.setFollowRedirects(HTTPC_FORCE_FOLLOW_REDIRECTS);
  http.setReuse(false);
  // Attach identity via headers (keep query param for temporary compatibility)
  attachIdentityHeaders(http);
  http.addHeader("Connection", "close");
  
  int httpCode = http.GET();
  
  if (httpCode != 200) {
    Serial.println("fetchJobs: HTTP error " + String(httpCode));
    http.end();
    client->stop();
    delete client;
    return false;
  }
  
  String payload = http.getString();
  
  // Use DynamicJsonDocument for larger response
  DynamicJsonDocument doc(4096);
  DeserializationError error = deserializeJson(doc, payload);
  
  if (error) {
    Serial.println("fetchJobs: JSON parse error");
    http.end();
    client->stop();
    delete client;
    return false;
  }
  
  if (!doc["success"]) {
    Serial.println("fetchJobs: API returned success=false");
    http.end();
    client->stop();
    delete client;
    return false;
  }
  
  // Parse jobs array
  JsonArray jobs = doc["jobs"].as<JsonArray>();
  cachedJobCount = 0;
  
  for (JsonVariant jobVar : jobs) {
    if (cachedJobCount >= MAX_JOBS) break;
    
    JsonObject job = jobVar.as<JsonObject>();
    cachedJobs[cachedJobCount].id = job["id"].as<String>();
    cachedJobs[cachedJobCount].title = job["title"].as<String>();
    cachedJobs[cachedJobCount].reward = job["reward"] | 0;
    cachedJobs[cachedJobCount].location = job["location"].as<String>();
    cachedJobs[cachedJobCount].createdAt = job["createdAt"].as<String>();
    cachedJobs[cachedJobCount].groupName = job["groupName"].as<String>();
    cachedJobCount++;
  }
  
  Serial.println("fetchJobs: Loaded " + String(cachedJobCount) + " jobs");
  
  // Track newest job for notifications
  if (cachedJobCount > 0) {
    lastSeenJobId = cachedJobs[0].id;
  }
  
  http.end();
  client->stop();
  delete client;
  return true;
}
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

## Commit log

2026-01-19 Initial release: Satoshi Pet open source firmware
    - Complete Arduino firmware for Heltec WiFi Kit 32 V3
    - Virtual pet that reacts to Bitcoin balance changes
    - Connects to Ganamos.earth for real-time sync
    - Mini games, feeding system, job notifications
    - Apache 2.0 license (firmware) + CERN-OHL-P v2 (hardware)
    - Full documentation: setup, flashing, wiring, BOM
    [case-v1.stl]
2026-01-19 Update BOM with correct Amazon links from satoshipet.com
2026-01-19 Rename firmware/ to satoshi_pet_heltec/ for Arduino IDE compatibility
    Arduino IDE requires sketch folders to match the .ino filename.
    This enables using the repo directly as the Arduino Sketchbook location.
2026-08-27 firmware: send device identity via headers (X-Device-Id/X-Pairing-Code) and attach through helper; keep deviceId query param for compatibility
2026-10-02 Fix: battery drain and button UX (#3)
    [config.cpp, economy.cpp, pet_blob.cpp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]
